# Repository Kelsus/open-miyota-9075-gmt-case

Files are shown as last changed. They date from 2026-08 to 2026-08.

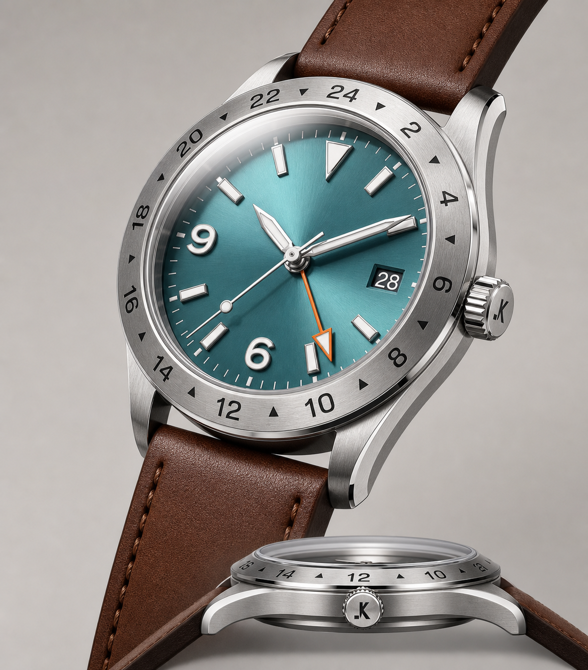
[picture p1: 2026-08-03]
mocks/fullwatchrender.png

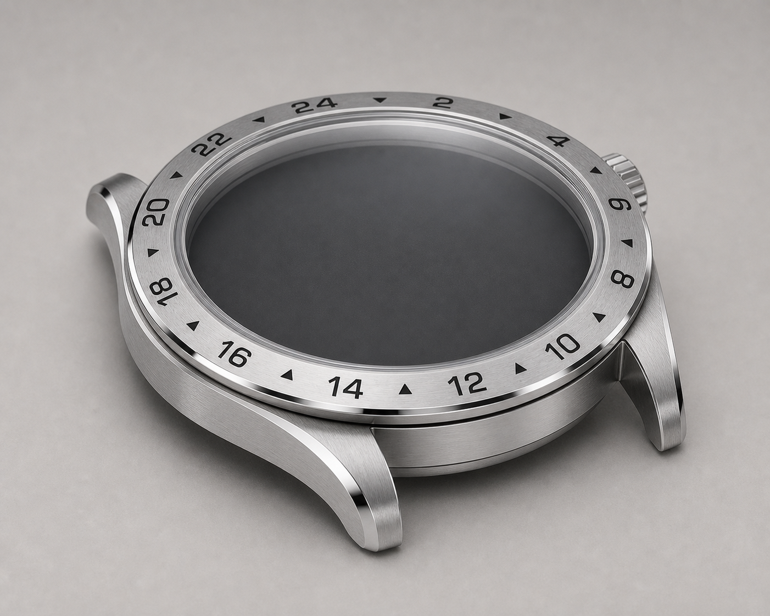
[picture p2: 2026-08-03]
mocks/threequarterviewofcase2.png

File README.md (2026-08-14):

# Open Miyota 9075 GMT case

## Why? (written by Jon Christensen)
I have been enjoying building watches, and felt like it would be a fun 
challenge to try to build a true GMT. The most available true GMT 
movement is the Miyota 9075. Unfortunately, I couldn't find any cases
to go with this movement on AliExpress or any of the other main watch
mod community ecommerce sites.

I tried buying the cheapest complete watch I could find (A 
Tissel available here: [https://tisellkr.com/](https://m.tisellkr.com/product/tisell-miyota-9075-gmt/49/), 
but it doesn't have an exhibition caseback, and I didn't love the 
way the bezel looked.

Fable 5 is getting good enough to be able to work with as a partner
to do CAD design. So I worked with it to build this design. It probably
took longer with Fable as a partner than it would have taken an expert
CAD user, but I'm pretty happy with how it turned out. And given that
the point of this exercise is just to get my hands on a few watch 
cases, I figured, why not just donate this case to the world as an 
open source project!?

Feel free to use it however you want, mod it how you like, use it as a 
starting point for your real watches in your real watch company. You
don't even have to mention where the design came from.

## The details (mostly written by AI.)

A complete, parametric watch case for the Miyota 9075 GMT movement,
written in [CadQuery](https://cadquery.readthedocs.io/) and verified by
a 120-assertion test suite. The repository contains everything needed to
study the design, rebuild it from parameters, 3D print a snap-together
prototype, or send it to a machine shop: STEP files for all nine parts,
drawing callouts for the features STEP cannot carry, print-adapted STLs,
and the scripts that generate all of it.

**Design review site:**
[kelsus.github.io/open-miyota-9075-gmt-case](https://kelsus.github.io/open-miyota-9075-gmt-case/)
shows the current revision with renders, the full spec table, and the
verification status. It is `docs/index.html`, regenerated by
`build_review.py` from the same model as everything else.

The code is MIT licensed. The hardware design is licensed under
CERN-OHL-P v2, which is the hardware equivalent of MIT. You can build,
modify, and sell cases from these files. See [Licensing](#licensing).

## The design

A 39 mm GMT sports watch case with a bidirectional 120-click 24-hour
bezel, sapphire crystal, screw-down crown, and a threaded exhibition
caseback. The bezel top is coned so the watch wears thinner than its
stack height. The lugs are cut from a revolved ring, so their junction
with the case is circular by construction and needs no fillets.

| | |
|---|---|
| Movement | Miyota 9075 (GMT, 24 h hand), cased on a machined movement ring |
| Diameter | 39.0 mm |
| Lug to lug | 47.9 mm |
| Height | 12.0 mm to the crystal apex |
| Lug width | 20 mm, drilled, Ø1.35 spring-bar holes |
| Dial | Ø31.0 |
| Crystal | Ø31.4 flat-top domed sapphire, I-ring gasket |
| Caseback | M32 x 0.5 threaded ring, Ø21 sapphire window |
| Bezel | steel 24 h, bidirectional, 120 clicks, ball detent |
| Water resistance | designed to 10 ATM (untested; see Status) |
| Material | 316L |

Dimensions that interact with the movement come from the official Miyota
9075 casing drawing (907500C0): 5.12 mm height, stem at 2.55 below the
dial plane, Ø25.60 register, and a hand-pivot chain of 2.70 above the
dial seat. The drawing is copyrighted, so it is not in this repository.
Get it from [Miyota](https://www.miyotamovement.com/).

## Repository map

| Path | What it is |
|---|---|
| `case_model.py` | The design. One parameter dict is the spec sheet; everything downstream regenerates from it. |
| `verify_case.py` | 120 hard assertions: stack heights, fits, clearances, sapphire stress, thread and gasket geometry, mesh-level regression checks. Run it after any change. |
| `scan_step.py` | Screens exported STEP files for geometry that breaks CAD importers (degenerate faces, self-intersecting shells). |
| `output/*.step` | The nine parts plus an assembly, ready for CAD or quoting. |
| `print_variant.py`, `PRINTING.md`, `output/print/` | FDM adaptation: snap fits replace the threads and the spring ring. Prints on a standard 0.4 mm nozzle; 0.2 mm recommended for the small parts. |
| `xometry_variant.py`, `xometry_drawings.py`, `output/xometry/` | CNC prototype kit with drawing sheets carrying the thread callouts and critical fits. |
| `MANUFACTURING.md` | How to get it made in metal: factory RFQ package and prototype-shop instructions. |
| `compare_mocks.py`, `mocks/` | Reference renders and a silhouette comparison harness used during design. |
| `render.py`, `build_review.py` | Preview renders and the single-file design review page (`docs/index.html`, served by GitHub Pages). |

## Building from source

```bash
python3 -m venv .venv
source .venv/bin/activate
pip install -r requirements.txt
python3 case_model.py     # writes output/*.step and *.stl
python3 verify_case.py    # 120 checks; exit 0 means all pass
```

The lug construction runs in a subprocess because OCCT segfaults are not
catchable in-process. If the build dies partway, run it again; the
subprocess retries are part of the design.

Two facts about the exports that will save you a bad afternoon:

1. **Threads are not modeled.** Threaded interfaces are plain cylinders
   at nominal diameter with the callout carried in drawings and comments
   (M32 x 0.5 caseback, S0.9 x 0.225 crown, tube press fits). If you
   send a STEP to a machine shop without the callouts, you get smooth
   bores.
2. **Exports are screened, not trusted.** OCCT booleans sometimes
   produce shells that import as phantom geometry in other CAD packages.
   `scan_step.py` gates every export; run it if you regenerate.

## 3D printing

`output/print/` contains a print-adapted variant: the caseback thread
becomes three cantilever snap tabs, the bezel spring ring becomes an
integral snap lip, the crystal and window get crush ribs, and the crown
gets a press pin. Print the included test coupon first to dial in your
printer's fit, then the case. PETG for the snap parts; PLA cracks.
Full instructions in [PRINTING.md](PRINTING.md).

## Making it in metal

[MANUFACTURING.md](MANUFACTURING.md) covers both routes: a watch case
factory (finished, polished, water-tested cases; this is how microbrands
work) and a prototype CNC shop (bare accurate metal, fast, no watch
finishing). `output/xometry/` is a ready-to-upload fitment kit for the
second route, with per-part drawing sheets and prototype substitutions
where true watch parts exceed general machining: a coarser caseback
thread, a pin crown instead of the threaded crown and tube, acrylic
instead of sapphire.

## Status

What has been done: the geometry is complete for all nine parts, passes
its 120 checks, imports into Fusion 360 without artifacts, and 3D prints
as a snap-together prototype. Every attachment is engineered and
documented: crystal gasket, bezel retention and detent, caseback thread
and O-ring, crown tube press fit, movement ring, spring bars.

What has not been done: no metal case has been machined from these files
yet, water resistance is a design target rather than a test result, and
the dial and hands are out of scope. Treat the design as a reviewed,
verified starting point, not a production-proven one. If you machine or
print it, open an issue with what you learn either way.

## Licensing

- **Software** (all `.py` files, the HTML template, and the docs): [MIT](LICENSE).
- **Hardware design** (the parametric geometry, STEP and STL files, and
  drawings; anything you manufacture from them):
  [CERN-OHL-P v2](LICENSE-HARDWARE), a permissive license that is the
  hardware equivalent of MIT.
- **Trademarks are not licensed.** The Kelsus name, the K monogram
  (`assets/kelsus-logo-k.svg`, also engraved on the crown and caseback),
  and the name Intercontinental identify Kelsus, Inc. If you make and
  distribute your own cases from this design, remove or replace the K
  and the names. The `kelsus_k_wire()` function and the engraving text
  parameters in `case_model.py` are the two places to change.

Both licenses disclaim warranty. A watch case holds a movement and sits
on a wrist; check the numbers yourself before trusting either.

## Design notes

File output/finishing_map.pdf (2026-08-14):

# Sheet 1 - Midcase

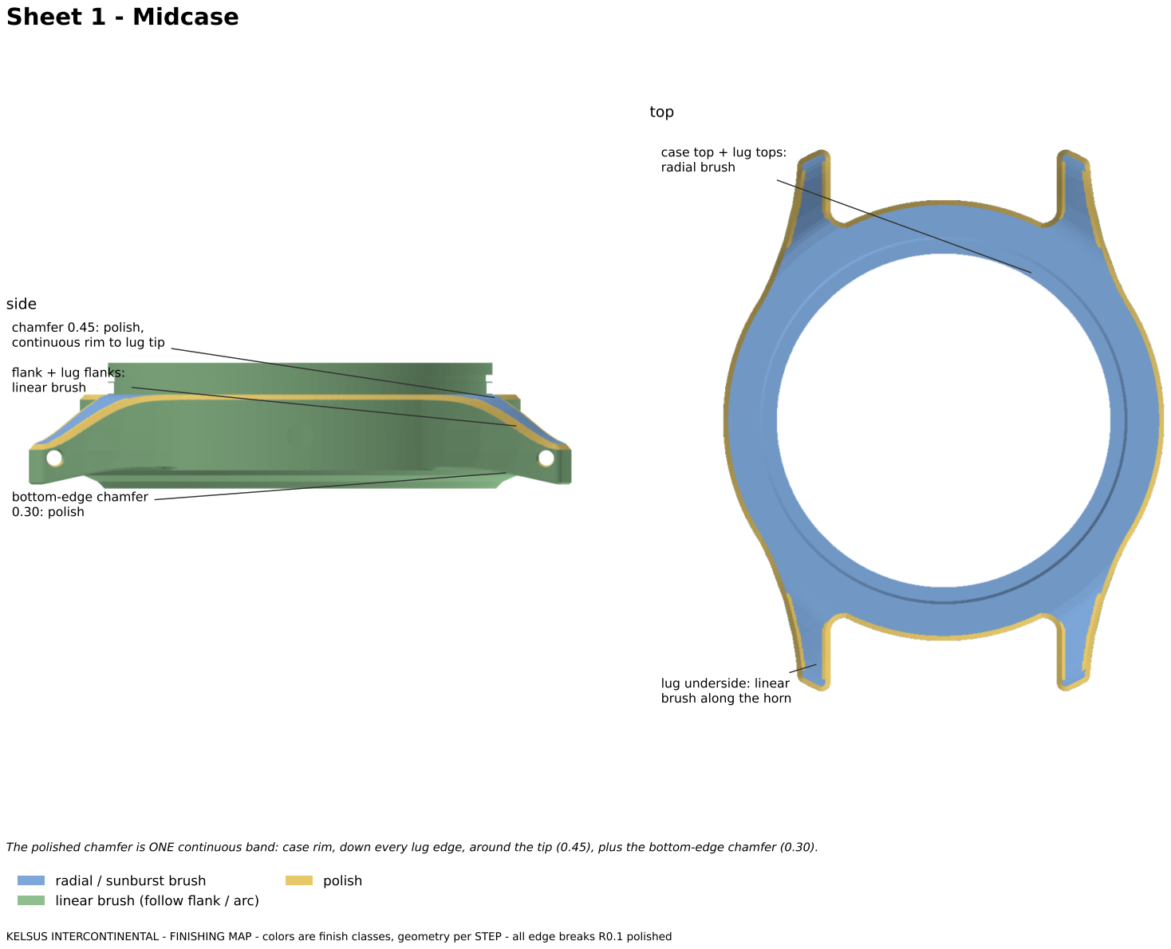
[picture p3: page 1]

flank + lug flanks:

linear brush

chamfer 0.45: polish,
continuous rim to lug tip

bottom-edge chamfer
0.30: polish

### side

case top + lug tops:
radial brush

lug underside: linear
brush along the horn

### top

The polished chamfer is ONE continuous band: case rim, down every lug edge, around the tip (0.45), plus the bottom-edge chamfer (0.30).

KELSUS INTERCONTINENTAL - FINISHING MAP - colors are finish classes, geometry per STEP - all edge breaks R0.1 polished

radial / sunburst brush
linear brush (follow flank / arc)

polish

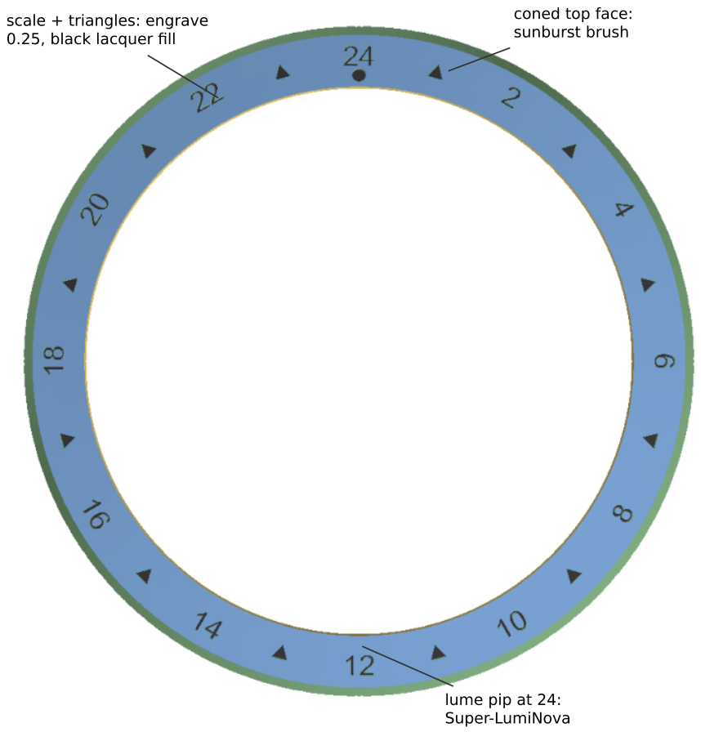
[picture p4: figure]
coned top face:; 0.25, black lacquer fill; lume pip at 24: Super-LumiNova

sunburst brush scale + triangles: engrave

### top

### side

# Sheet 2 - Bezel

radial / sunburst brush
linear brush (follow flank / arc)

polish
engraved (black lacquer fill on bezel)

# Sheet 3 - Caseback ring and crown

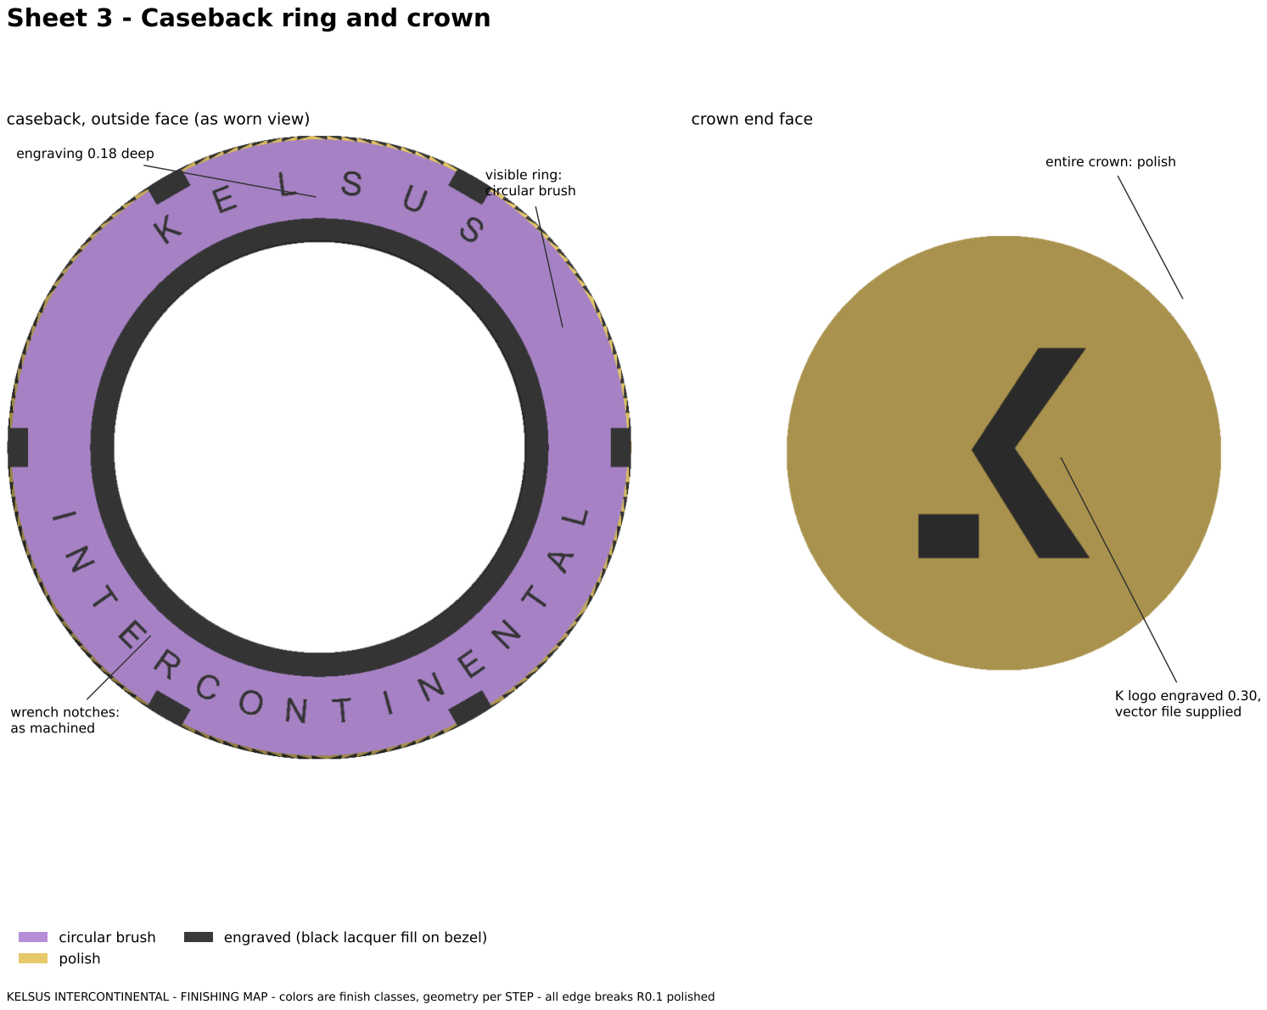
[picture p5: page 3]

visible ring:
circular brush

engraving 0.18 deep

wrench notches:
as machined

### caseback, outside face (as worn view)

entire crown: polish

K logo engraved 0.30,
vector file supplied

### crown end face

circular brush
polish

engraved (black lacquer fill on bezel)

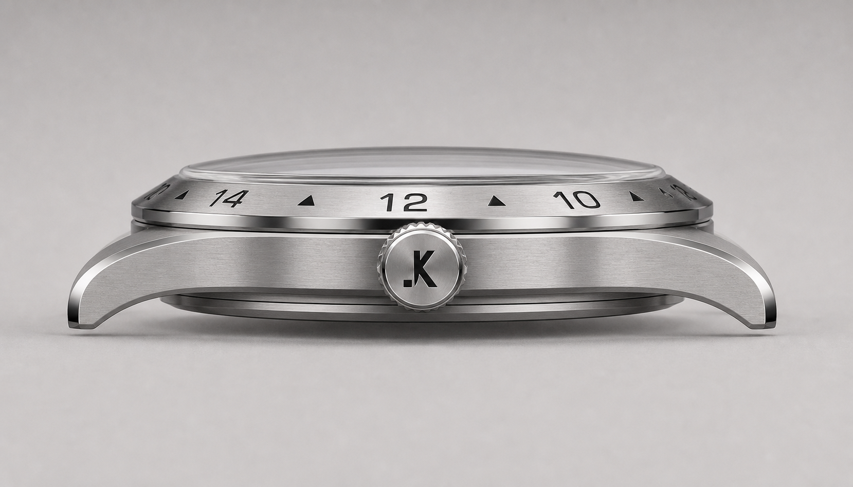
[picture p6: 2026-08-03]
mocks/crownsideviewofcase.png

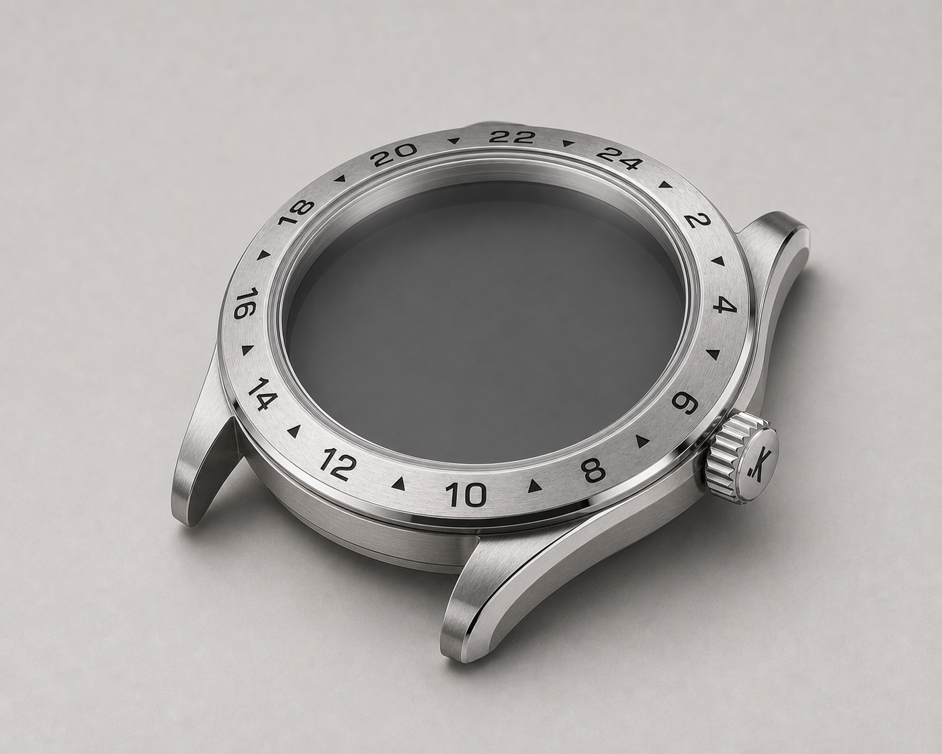
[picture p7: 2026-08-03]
mocks/threequarterviewofcase.png

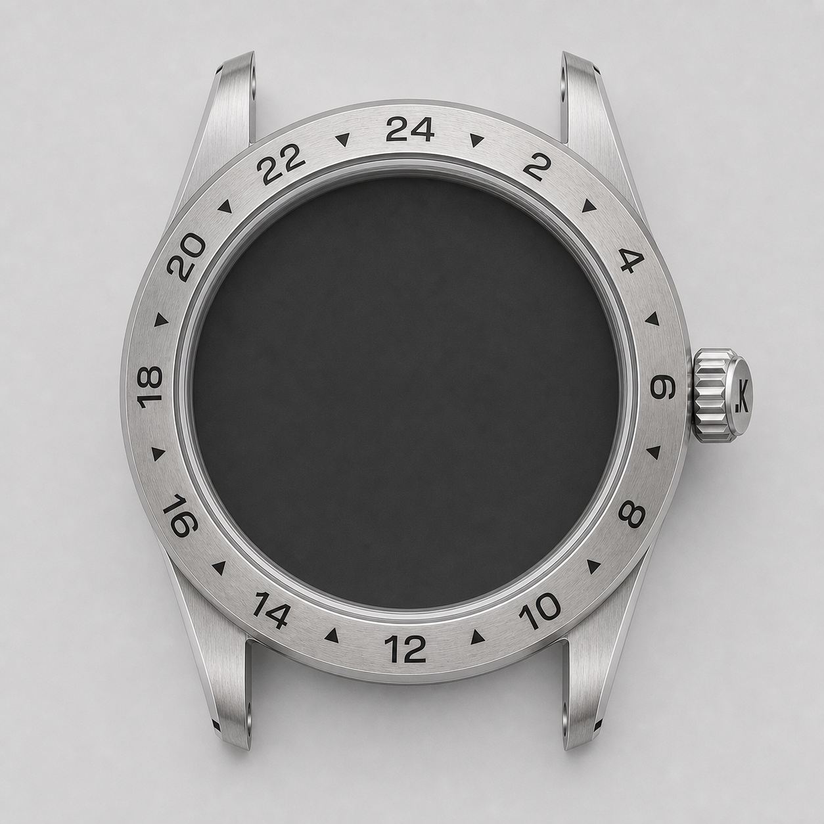
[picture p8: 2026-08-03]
mocks/topdownviewofcase.png

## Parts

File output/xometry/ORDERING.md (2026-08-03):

# Xometry order guide: fitment kit

Everything in this folder goes into one Xometry quote. Seven parts, all
1:1 with the master design except three prototype substitutions (coarser
caseback thread, pin crown instead of the threaded crown+tube, acrylic
instead of sapphire). Together they let you fully case a Miyota 9075:
movement + ring into the case, caseback screws in and sets the preload,
dial-side and hand clearance visible through the acrylic crystal, stem
alignment through the tube bore, bezel and crown for the complete look.

## Upload

Instant quote → CNC machining → upload all 7 STEPs. Then **attach
`intercontinental_fitment_kit_drawings.pdf` to every part.** The STEPs
carry no thread geometry; without the drawing you receive smooth bores
instead of threads.

## Per-part settings

| File | Process | Material | Finish | Qty |
|---|---|---|---|---|
| x01_midcase.step | CNC, 5-axis | Aluminum 6061-T6 | As machined (or bead blast) | 1 |
| x02_bezel.step | CNC | Aluminum 6061-T6 | As machined | 1 |
| x04_caseback.step | CNC | Aluminum 6061-T6 | As machined | 1 |
| x06_crown_proto.step | CNC (lathe) | Aluminum 6061 or 303 SS | As machined | 1 |
| x08_movement_ring.step | CNC | Acetal (Delrin/POM) | As machined | 1 |
| x03_crystal_acrylic.step | CNC | Acrylic (PMMA), clear | As machined | 1 |
| x05_window_acrylic.step | CNC | Acrylic (PMMA), clear | As machined | 1 |

Tolerance option: pick the tier that honors attached drawings (their
standard is a blanket ±0.13, which is not enough for the H7/Js8 fits;
the drawing callouts override where noted). Threads: M30×1.0 internal (case) and
external (back) are called out on sheets 1 and 3.

## Expect from DFM review

- Warnings on the tiny cosmetic features (0.25 engravings, 120 scallops,
  coin edge, Ø0.65 ball pocket). All are marked "best effort / may be
  omitted" on the drawings. Accept their recommendation; none affect
  fitment.
- Possible upcharge or pushback on the M30×1.0 internal thread and the
  deep 5-axis lug undersides. Both are legitimate work; pay it or ask
  for their alternative.
- If a part is rejected as unmachinable-at-price (most likely the coin
  edge or crown), drop the feature rather than the part.

## Budget guidance

The midcase (full 5-axis) dominates cost. If the quote shocks you, order
in two waves: **wave 1 = x01 + x04 + x08** (that's the complete movement
fitment test), wave 2 = bezel/crown/acrylics (look and feel). Aluminum
first; reorder the keepers in 316L once the fit is proven. Expect
roughly 3 to 5 times the aluminum price and a longer lead.

## When the parts arrive

1. Deburr check: run a fingernail around the dial pocket and crystal
   seat; any burr there scratches the dial.
2. Drop the 9075 (no dial) into the movement ring, ring into the case.
   It should register with zero rock.
3. Fit the dial (Ø31.0): it must clear the rehaut all round.
4. Stem check: cut a stem to length, thread into the movement, confirm
   it exits the Ø2.48 bore centered with no bind. Slide the crown pin in.
5. Caseback: screw in (M30×1.0). It should seat fully and just clamp the
   movement ring with no rattle. The design carries 0.02 preload; with
   ±0.05 aluminum tolerances expect anything from a light rattle to a
   light pinch. Note which you got, it calibrates the steel run.
6. Hands + acrylic crystal: press hands at 12:00:00, seat the crystal,
   verify hour/minute/GMT/seconds all clear the crystal underside.
7. Bezel: seat it on the boss over the groove. With no spring ring it
   lifts off again; that is expected. Check the reveal band is even and it clears the crystal.
8. Bracelet: spring bars through the Ø1.35 holes, end link against the
   Ø39 land, check for rock.

Log every deviation. That list is what gets tuned before the 316L run
or the factory RFQ.

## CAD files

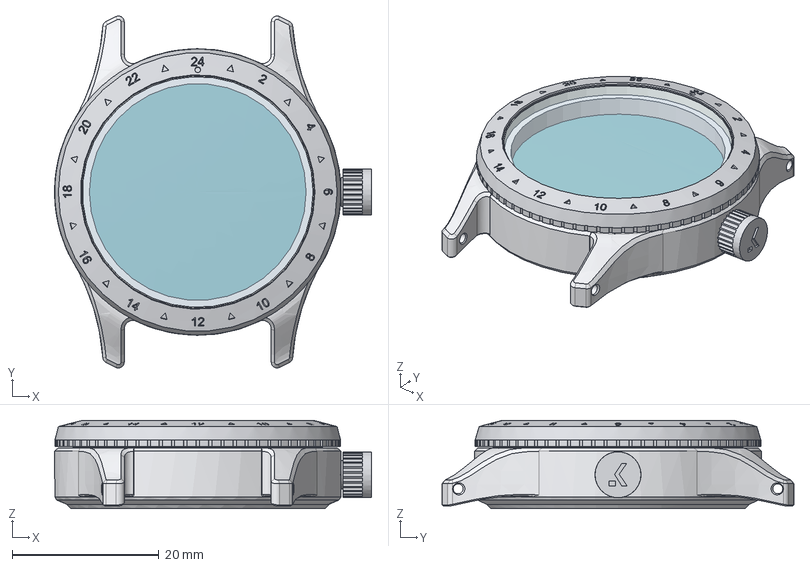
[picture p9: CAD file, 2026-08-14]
output/assembly.step
43.1 x 47.9 x 12.0 mm
midcase
bezel
crystal
caseback_ring
caseback_sap
crown
tube
movement_ring
bezel_spring
movement_ref
dial_ref
iring_gasket_installed
bezel_oring_installed

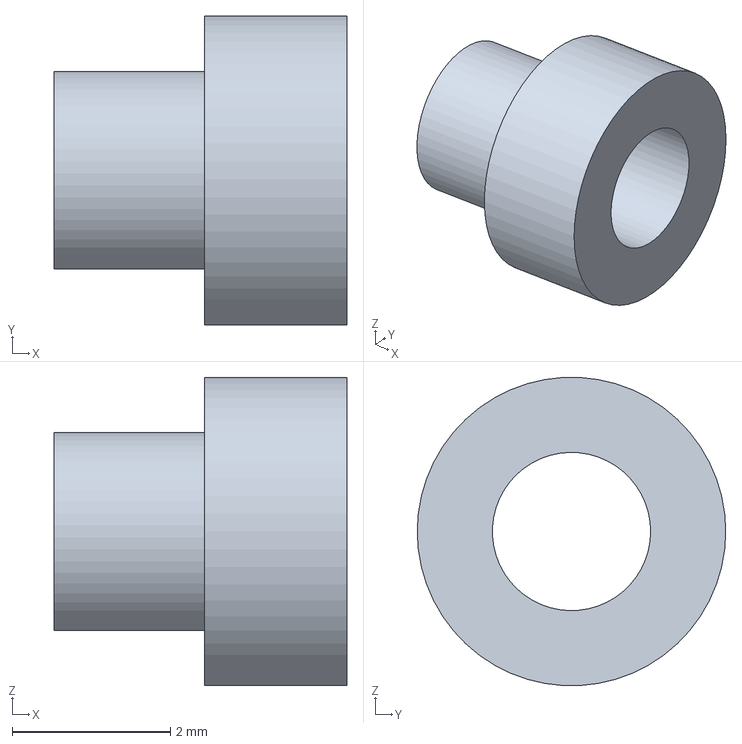
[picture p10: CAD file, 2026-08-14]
output/07_crown_tube.step
3.70 x 3.90 x 3.89 mm

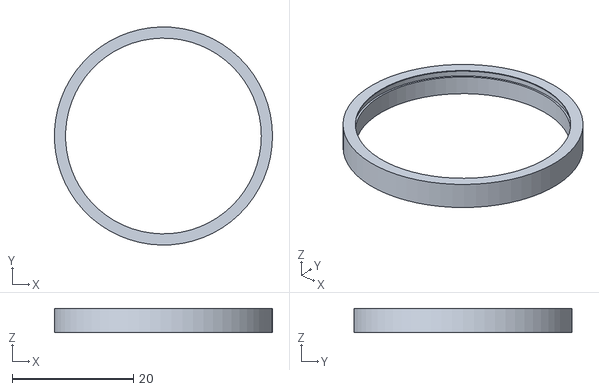
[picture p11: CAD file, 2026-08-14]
output/print/p00_snap_coupon.stl
36.0 x 36.0 x 4.00

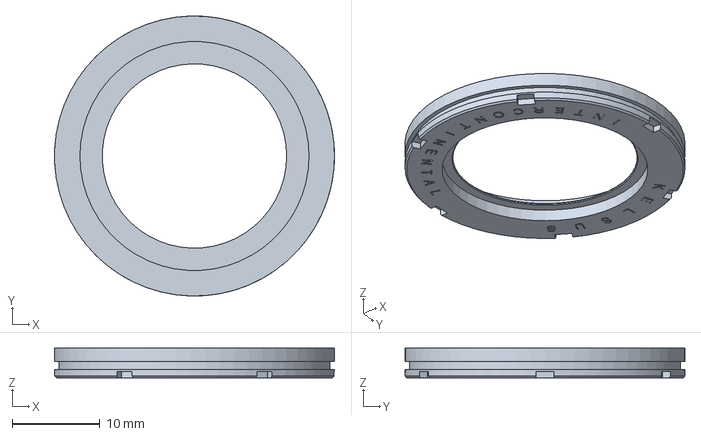
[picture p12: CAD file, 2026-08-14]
output/xometry/x04_caseback.step
31.9 x 31.9 x 3.40 mm

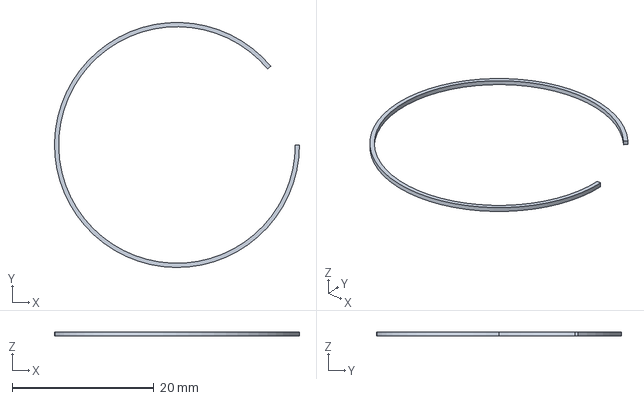
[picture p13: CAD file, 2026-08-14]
output/09_bezel_spring.step
34.6 x 34.6 x 0.6 mm

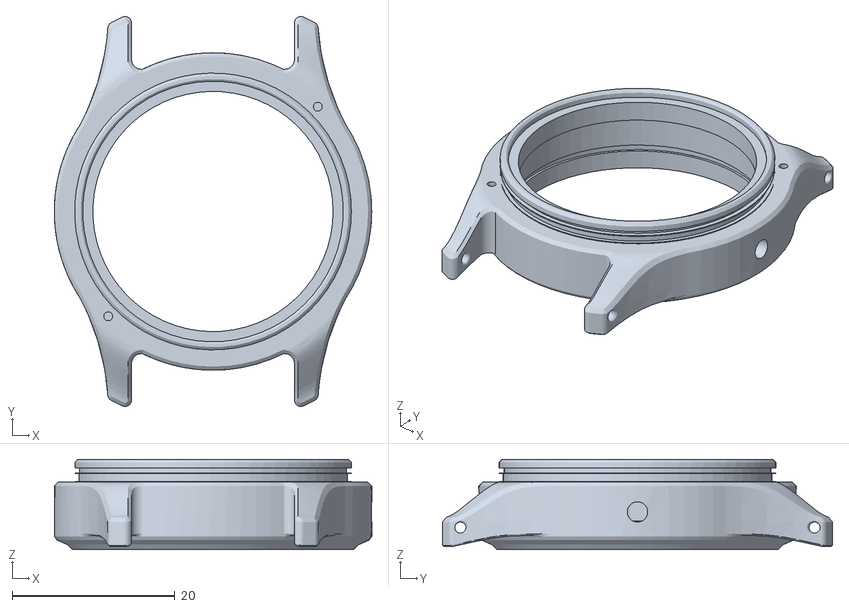
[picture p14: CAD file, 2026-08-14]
output/print/p01_case.stl
39.0 x 47.9 x 11.1

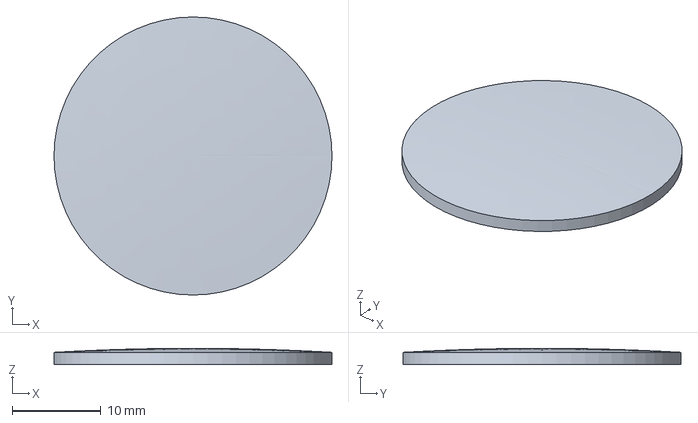
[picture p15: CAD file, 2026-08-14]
output/xometry/x03_crystal_acrylic.step
31.4 x 31.4 x 1.85 mm

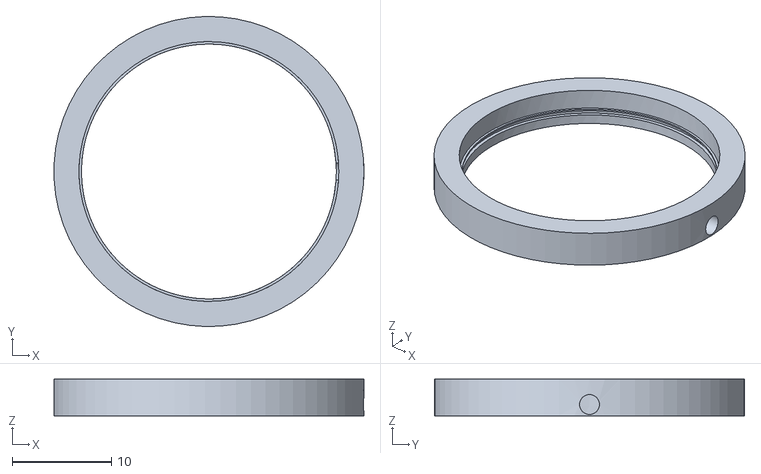
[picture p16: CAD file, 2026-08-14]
output/print/p08_movement_ring.stl
31.2 x 31.2 x 3.69

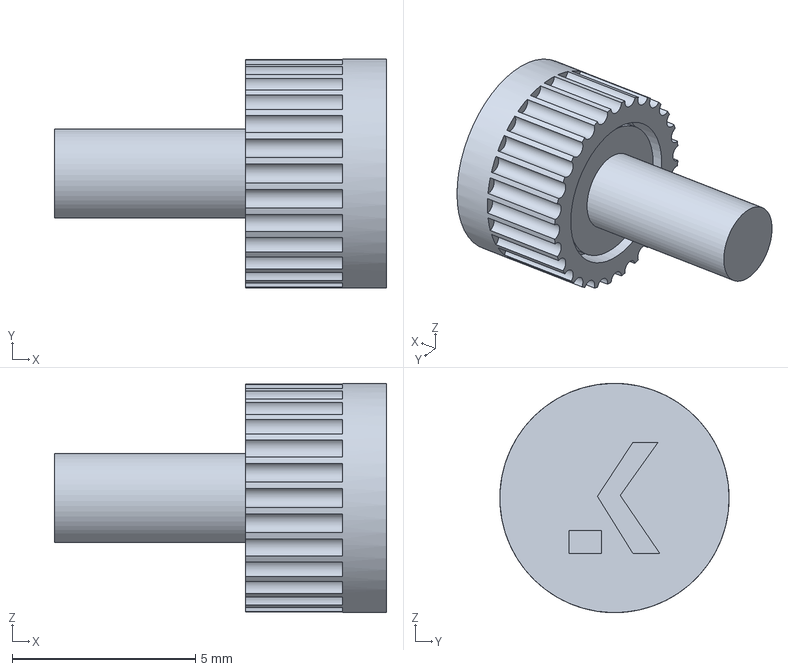
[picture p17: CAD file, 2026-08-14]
output/xometry/x06_crown_proto.step
9.05 x 6.25 x 6.25 mm

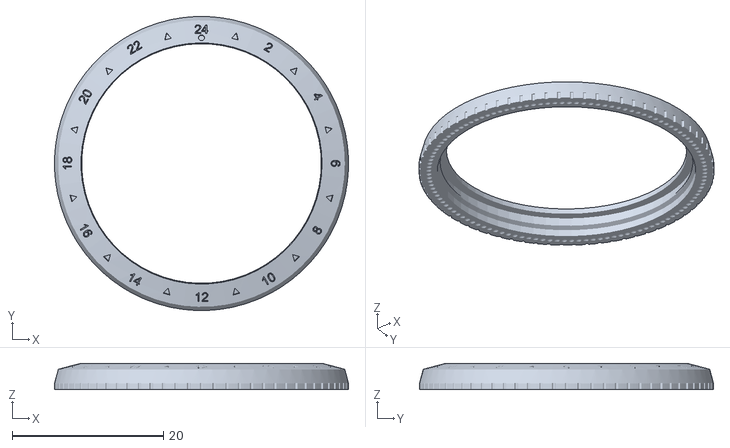
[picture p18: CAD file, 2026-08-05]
output/print/p02_bezel.stl
38.9 x 38.9 x 3.50

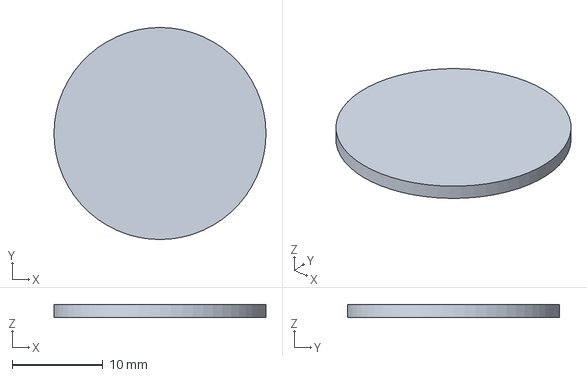
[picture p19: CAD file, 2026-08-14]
output/05_caseback_sapph.step
23.4 x 23.4 x 1.40 mm

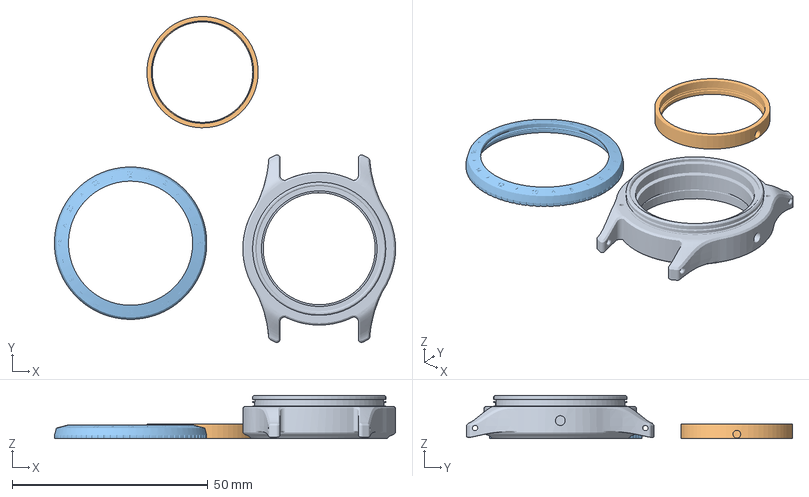
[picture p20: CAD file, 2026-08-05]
output/print/reprint_case.3mf
87.1 x 83.2 x 11.1 mm
p01_case.stl
p08_movement_ring.stl
p02_bezel.stl

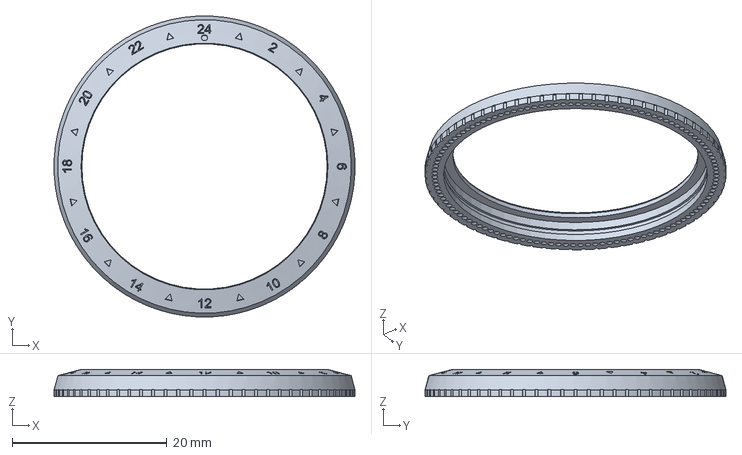
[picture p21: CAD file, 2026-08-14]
output/xometry/x02_bezel.step
38.9 x 38.9 x 3.50 mm

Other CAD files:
output/01_midcase.step
output/xometry/x08_movement_ring.step
output/08_movement_ring.step
output/print/p04_back.stl
output/xometry/x01_midcase.step
output/02_bezel.step
output/03_crystal.step
output/04_caseback_ring.step
output/06_crown.step
output/10_iring_gasket.step
output/11_bezel_oring.step
output/print/p03_crystal.stl
output/print/p05_window.stl
output/print/p06_crown.stl
output/print/print_case.3mf
output/print/testprint.3mf
output/xometry/x05_window_acrylic.step

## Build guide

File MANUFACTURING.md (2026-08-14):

# Getting the case made in metal

Two routes, and they answer different questions.

**Route A: a watch case factory.** You are buying a finished case:
machined, brushed and polished to watch grade, threads cut, sapphires
pressed with gaskets, crown and tube fitted, bezel clicking, water
tested, assembled. The factory sources the companion parts (sapphire,
gaskets, crown, tube, spring bars) from its local ecosystem for a few
dollars each. This is how microbrands work.

**Route B: a prototype CNC shop (Xometry, Protolabs, or similar).** You
are buying the exact geometry in the STEP file, in metal, fast, and
nothing else. No watch finishing (machine shop polishing is not watch
polishing), no gaskets, no sapphire, no assembly, no water resistance.
Everything after the machining is on you, and case finishing and crystal
pressing are hard to do well at home.

**Recommendation: both, in sequence.** Order the midcase from a
prototype shop in aluminum first, to hold the metal shape in hand and
check the bracelet fit, and send the full package to two or three case
factories for samples in parallel. Machining the full set at a prototype
shop in 316L costs more than factory samples and arrives less finished.
The exception is confidentiality: assume anything sent to a case factory
can be reused by them. If that is unacceptable, use Route B for
everything and accept the cost and the finishing work.

---

## The mistake to avoid

**The STEP files contain no thread geometry.** Threaded interfaces are
plain cylinders with the thread carried as a callout, which is standard
CAD/CAM practice. Upload a STEP to a quote engine without the callouts
and you get smooth bores. Every RFQ must carry these:

| Interface | Callout | Where |
|---|---|---|
| Caseback to case | M32 x 0.5, internal 6H (case), external 6g (back) | case bore Ø32.0 region, z 0 to 3.5 |
| Crown to tube | S0.9 x 0.225 (Miyota 9075 stem thread standard) | crown bore |
| Tube to case | press fit: tube shank Ø2.50 s6 into case bore Ø2.48 H7 | crown side, stem axis 4.62 above the back plane |
| Tube thread (crown screws onto it) | Ø3.9 x 0.35, depth 0.22 | tube OD |

## RFQ package contents

Send: `output/*.step` (9 parts plus the assembly), renders or the review
page for finish intent, reference images, and the spec tables below. Say
this in the cover message: the STEP is master geometry; threads and
finishes are per the spec sheet; where marked substitutable, the factory
may propose its standard equivalent parts.

### Critical dimensions (hold these)

| Feature | Dim | Tol |
|---|---|---|
| Case Ø | 39.00 | ±0.05 |
| Lug to lug | 47.90 | ±0.10 |
| Lug gap (bracelet) | 20.00 | +0.15 / −0 |
| Total height (back to crystal apex) | 12.02 | ±0.10 |
| Spring-bar holes | Ø1.35 ±0.05, 90° csk to Ø1.65 | position ±0.05 |
| Ø39.0 cylindrical end-link land | down to z 1.60 from the back plane | |
| Movement: Miyota 9075 | register Ø25.60 Js8, flange relief Ø26.0 x 2.05 deep | per Miyota drawing 907500C0 |
| Dial | Ø31.0; loads from the back through the caseback thread and pass bore, retained by the rehaut ledge | |
| Dial pass bore | Ø31.40 | H8 |
| Crystal bore | Ø32.00 H7; crystal Ø31.40 flat-top domed sapphire, I-ring gasket 0.35 wall, 0.10 diametral crush | |
| Bezel bore and boss | Ø34.10 bore on Ø34.00 boss, retention groove floor Ø32.80 | bore H8, boss h7 |
| Caseback sapphire | Ø23.4 x 1.4, view Ø21.0, pressed from outside against an internal ledge | |
| Stem axis height | 4.62 above the caseback plane | ±0.05 |

### Sealing (target 10 ATM, test to ISO 22810 at 10 bar)

- Caseback: radial O-ring, cs 0.70, in an OD groove (0.9 wide x 0.5 deep)
- Crown: O-ring cs 0.70 inside the crown, gasket at the tube
- Crystal: I-ring gasket, 0.35 wall (nylon or PA)
- Bezel: centring O-ring cs 0.70 in the boss groove (damping, not sealing)

### Bezel action

Bidirectional, 120 clicks. As designed: a spring-loaded ball in the case
shoulder rides 120 scallops (Ø0.50 ball seats, 0.18 deep, on Ø36.4) in
the bezel underside; the bezel is retained by a slit spring ring (part
09, free OD Ø34.6) engaging the boss groove. Substitutable: a factory's
standard ball click and spring washer retention is acceptable if the
bezel height, reveal, and exterior geometry are unchanged.

### Finishing map

`python3 build_finishing_map.py` renders this map as a color-coded PDF
(`output/finishing_map.pdf`) to attach to an RFQ.

- Case top faces and lug tops: radial brush
- Case flank: horizontal brush; lug flanks: brush following the arc
- All chamfers (shoulder 0.45, lug top, case bottom 0.30): polished
- Bezel coned top face: sunburst brush; long outer bevel: polished; coin edge: cut sharp
- Bezel numerals and triangles: engraved 0.25, black lacquer fill; lume
  pip Ø0.8 at the 24 position, recess 0.35 deep, Super-LumiNova fill
- Caseback ring: circular brush; engraving "KELSUS INTERCONTINENTAL"
  0.18 deep, filled or bare per sample
- Crown: polished, K logo engraved on the end face (SVG artwork in
  `assets/`; do not redraw it)
- Edge breaks everywhere else: R0.1 ("break sharp edges")

### Substitutable against not negotiable

The factory may substitute, with equivalents proposed in DFM: gaskets
and O-rings; the crown and tube as a bought-in assembly (with the K logo
face); the bezel click mechanism; the movement ring material (POM or
brass); the spring ring. Not negotiable: the exterior geometry and the
dimensions above, the movement interfaces, dial Ø31.0, stem height, the
bracelet interface, sapphire plus exhibition back, screw-down crown, and
the finishes.

---

## Route A: case factory, step by step

1. Shortlist 2 or 3 watch case factories rather than trading companies.
   Ask: do you machine in house, and can we video call the shop floor?
   Ask for microbrand references and a photo of a case they made with a
   coned engraved bezel and an exhibition back.
2. Send the RFQ package. Ask for DFM feedback, sample price and lead
   time, production MOQ and unit price at 50, 100, and 300, and a
   written change log. Factories normalize geometry to house standards
   without telling you; require every deviation from the STEP to be
   listed for approval.
3. Expect sample pricing in the rough range of $200 to $800 per complete
   case and 4 to 8 weeks (verify; these numbers move). Pay for samples
   from two factories in parallel; the extra cost is small and the
   comparison is worth it.
4. When samples arrive, inspect against the checklist below with a 9075
   and a dial blank on hand.
5. Then discuss production. Typical case MOQs are 50 to 100; some shops
   do 20 to 30 at a premium.

On IP: an NDA with a case factory is worth asking for and worth little.
Assume the geometry can end up in their catalog. If that is
unacceptable, use Route B at higher cost, or split parts across
suppliers.

## Route B: prototype CNC shop, step by step

A real data point first (August 2026): Xometry's instant quote for the
midcase alone, aluminum 6061, quantity 1, standard ±0.13 tolerance and
no threads, was $670. The threads and the tight fits from the drawings
would raise that. If a printed prototype has already answered the form
and fit questions, Route A samples deliver more per dollar; a US
instant-quote shop at quantity 1 is the most expensive way to hold this
case in metal. Cheaper metal options: overseas instant-quote CNC
services (JLCCNC, PCBWay, RapidDirect) quote the same uploads at a
fraction of the US price, and an SLM 316L metal print of the midcase
(rough surface, no working fits, real steel weight) runs cheaper still.

1. Upload `01_midcase.step`, and `02_bezel.step` if the look matters for
   this round. Process: CNC machining, 5-axis. Material: aluminum
   6061 for a fit check round; 316L later runs near 3 to 5 times the
   price and slower.
2. Attach a drawing or manufacturing notes PDF carrying the thread
   callouts and criticals from the tables above. Without an attached
   drawing everything defaults to a blanket tolerance near ±0.13 and
   smooth bores. `output/xometry/` contains a ready-made fitment kit
   with per-part drawing sheets.
3. Finish: as machined or bead blast. Do not pay for shop polishing on a
   fit check.
4. Skip at the prototype shop: crown, tube, spring ring, gaskets, and
   sapphires. These are bought parts (crown and tube from a watch parts
   supplier, sapphires from a sapphire house).

## Sample inspection checklist (either route)

- [ ] 9075 plus movement ring drops into the register; no rock; clamp screws reach
- [ ] Stem hole aligns with the movement stem (height 4.62, no bind on a real stem)
- [ ] Dial Ø31.0 seats in the pocket; no rehaut shadowing at the edge
- [ ] Caseback threads in for 4 or more full turns, seats with the gasket, notches take a wrench
- [ ] Crystal pressed flush, no gasket extrusion visible, no stress rings
- [ ] Bezel: 120 clean clicks, no wobble, even reveal all round
- [ ] Crown: screws down and engages 3 or more turns (ask for orientation-timed threading only if the K angle matters; it costs)
- [ ] Bracelet: end link seats on the Ø39 land without rocking; spring bars go in and out without force
- [ ] Water test certificate at 10 bar
- [ ] Finish: brush grain directions per the map, lacquer fill clean in the numerals, engraving depth even
- [ ] Weight near 49 g for the bare 316L case

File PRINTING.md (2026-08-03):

# 3D printing the case

A 1:1 snap-together prototype of the case. It is a form, feel, and
assembly prototype: wrist presence, lug drape, bezel proportions, end
link and dial fit. It is not a functional watch case. The machined
design's fasteners are below FDM resolution (the M30 x 0.5 caseback
thread, the S0.9 crown thread, and the 0.35 mm steel bezel spring ring),
so `print_variant.py` derives adapted parts where every interface is a
snap or press fit sized for plastic. Files are in `output/print/`.

| File | Replaces | How it attaches |
|---|---|---|
| `p00_snap_coupon.stl` | nothing | 20 minute test ring: dial in the caseback snap before the long case print |
| `p01_case.stl` | 01 midcase | snap bore Ø30.30 with a groove replaces the thread; straight Ø2.5 crown hole; boss lead-in chamfer |
| `p02_bezel.stl` | 02 bezel + 09 spring ring | integral snap lip (Ø33.35) clicks over the boss into the retention groove and still rotates |
| `p03_crystal.stl` | 03 crystal + gasket | 6 crush ribs press into the Ø32.0 bore |
| `p04_back.stl` | 04 back + M30 thread | 3 cantilever snap tabs click into the case groove |
| `p05_window.stl` | 05 sapphire | clear disc, 3 crush ribs, presses into the back from outside |
| `p06_crown.stl` | 06 crown + 07 tube | integral Ø2.42 pin presses into the crown hole |
| `p08_movement_ring.stl` | 08 ring | drops into the case bore as designed |

`output/print/` also contains Bambu Studio project files (`*.3mf`) from
a successful print run on a Bambu Lab H2C with a 0.2 mm nozzle. If you
run Bambu Studio, open one of those and skip the setup below.

## Materials and nozzle

- **PETG** for the case, bezel, back, and movement ring. The snaps need
  PETG's strain headroom near 5 percent; PLA whitens or cracks on the
  caseback tabs and the bezel lip.
- **Clear PETG** or PC for the crystal and window. They print
  translucent rather than glass clear. For a clearer window, cut 1.5 mm
  acrylic to Ø23.2 and skip `p05`.
- Crown: any material.
- A **0.2 mm nozzle** is recommended for the bezel, crown, crystal, and
  window (numerals, coin edge, logo, ribs). 0.4 mm works for the case,
  back, coupon, and movement ring. With only a 0.4 mm nozzle everything
  still prints; the engraving detail is what you lose.

## Slicer setup

Settings below are for Bambu Studio and carry over to any modern slicer.
Global for all parts: 0.08 to 0.12 mm layers, 4 walls, 25 percent gyroid
infill, seam position "Aligned" (put it at 12 o'clock on the case so it
hides between the lugs).

Per part:

| Part | Orientation on plate | Supports |
|---|---|---|
| coupon | as exported (flat) | none |
| case | caseback face down (as exported) | tree supports under the lug undersides only; with a dual-nozzle printer, use a support interface material that the body does not bond to, which leaves glassy undersides |
| bezel | skirt down (as exported) | none; the internal ceiling bridges Ø32 to Ø34, enable "thick bridges" |
| back | engraved face down (as exported) | none; the engraving prints into the first layers and stays legible |
| crystal | seat down, dome up | none |
| window | flat down | none |
| crown | logo face down, pin up | none |
| movement ring | flat down | none |

## Print order

1. **Print `p00_snap_coupon` and `p04_back` first.** Click the back into
   the coupon: it should seat with a firm push and a click, and take
   real effort to pry back out (pry at the wrench notches).
   - Too tight or no click: set X-Y hole compensation +0.05 to +0.10 on
     the coupon (and later the case), or sand the three bumps.
   - Too loose: go the other way, or reprint the back scaled 100.3
     percent in X-Y only.
   - Carry the winning compensation into the case print.
2. Print the case (the long print) and the rest in any order.

## Assembly

1. **Movement ring** drops into the case from the back, clamp band up.
2. **Crystal**: press into the top bore with a flat block until it stops
   on the seat. The bore's lead-in chamfer does the guiding.
3. **Bezel**: set it square on the boss and press straight down with
   both thumbs. The lip climbs the boss chamfer, snaps into the groove,
   and the bezel then spins with a little play. The prototype has no
   detent clicks; the 0.18 mm scallops and the ball are below printable
   scale.
4. **Caseback**: align and press until the three tabs click into the
   groove. Remove by pushing from the crystal side with the crystal
   out, or pry at the wrench notches.
5. **Window**: press into the back's pocket from the outside.
6. **Crown**: the printed crown hole comes out near Ø2.3 to 2.4. Run a
   2.4 mm drill through it if available, then press the crown pin in.
   Leave it dry so the depth can be adjusted; a dot of CA glue once it
   is right.
7. **Spring bars**: the Ø1.35 lug holes print near Ø1.15. Open them
   with a 1.4 mm drill, then fit Ø2.0 spring bars and end links as
   normal.

## What this prototype can and cannot tell you

**Good for:** wrist feel at 47.9 x 39 x 12.0, lug drape and stance,
bezel diameter and height proportions, end link and bracelet fit on the
Ø39 land, dial opening at Ø31, crown position and reach.

**Not representative:** thread feel, water resistance (none), bezel
detents, surface finish, weight (a PETG case is near 8 g against 49 g
in steel; add the movement and bracelet for a fairer wrist impression),
and the crystal optics.

**Real movement caution:** the case will hold a Miyota 9075 for a dial
and stem alignment check, but printed plastic sheds static and debris.
Keep the movement in its ring, dust it before it goes back into anything
that matters, and do not force the stem: printed hole tolerances are
plus or minus 0.1 at best.

## Regenerating

After any change to the master model:

```bash
python3 case_model.py && python3 print_variant.py
```

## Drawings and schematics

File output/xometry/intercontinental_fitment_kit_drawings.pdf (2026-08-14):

### CASEBACK THREAD

### CRYSTAL BORE

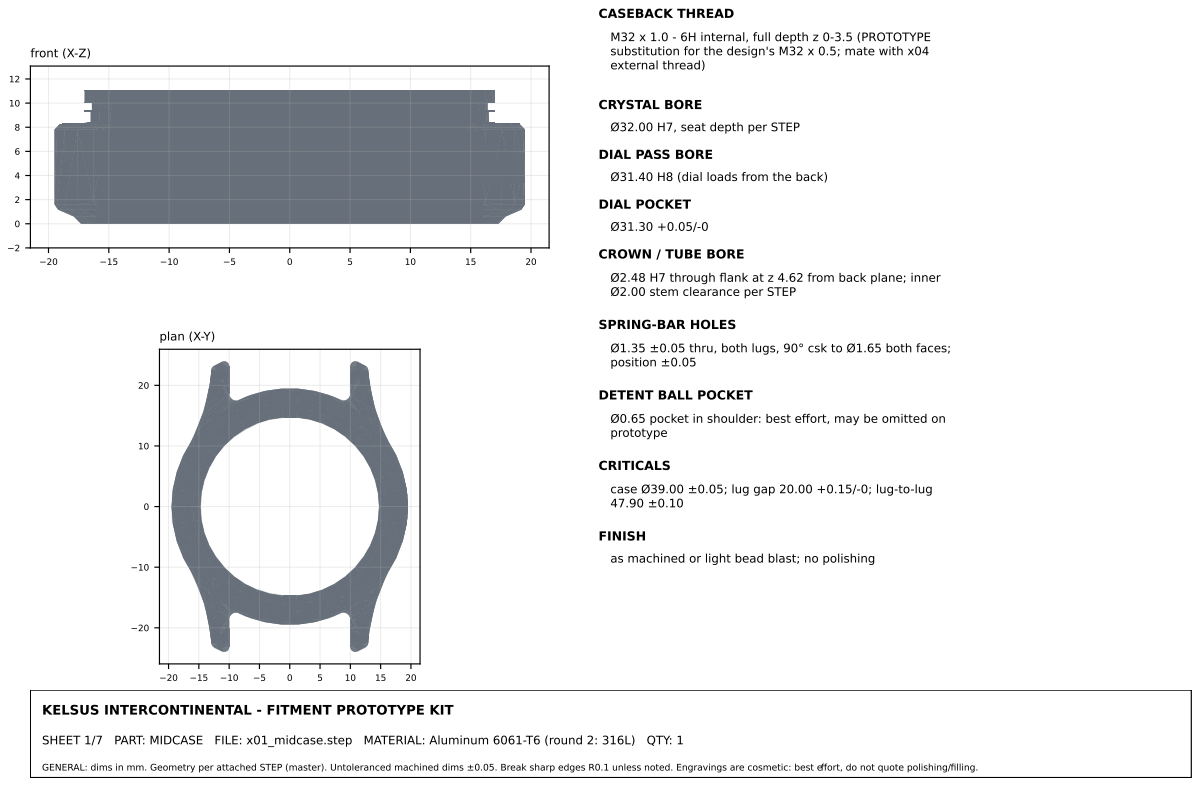
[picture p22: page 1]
front (X-Z); plan (X-Y); DIAL POCKET; CRITICALS; FINISH

M32 x 1.0 - 6H internal, full depth z 0-3.5 (PROTOTYPE
substitution for the design's M32 x 0.5; mate with x04
external thread)

Ø32.00 H7, seat depth per STEP

DIAL PASS BORE

Ø31.40 H8 (dial loads from the back)

CROWN / TUBE BORE
Ø2.48 H7 through flank at z 4.62 from back plane; inner
Ø2.00 stem clearance per STEP

SPRING-BAR HOLES

Ø1.35 ±0.05 thru, both lugs, 90° csk to Ø1.65 both faces;
position ±0.05

DETENT BALL POCKET
Ø0.65 pocket in shoulder: best effort, may be omitted on
prototype

case Ø39.00 ±0.05; lug gap 20.00 +0.15/-0; lug-to-lug

as machined or light bead blast; no polishing

KELSUS INTERCONTINENTAL - FITMENT PROTOTYPE KIT

SHEET 1/7 PART: MIDCASE FILE: x01_midcase.step MATERIAL: Aluminum 6061-T6 (round 2: 316L) QTY: 1

GENERAL: dims in mm. Geometry per attached STEP (master). Untoleranced machined dims ±0.05. Break sharp edges R0.1 unless noted. Engravings are cosmetic: best effort, do not quote polishing/filling.

### BORE

### INTERNAL GROOVE

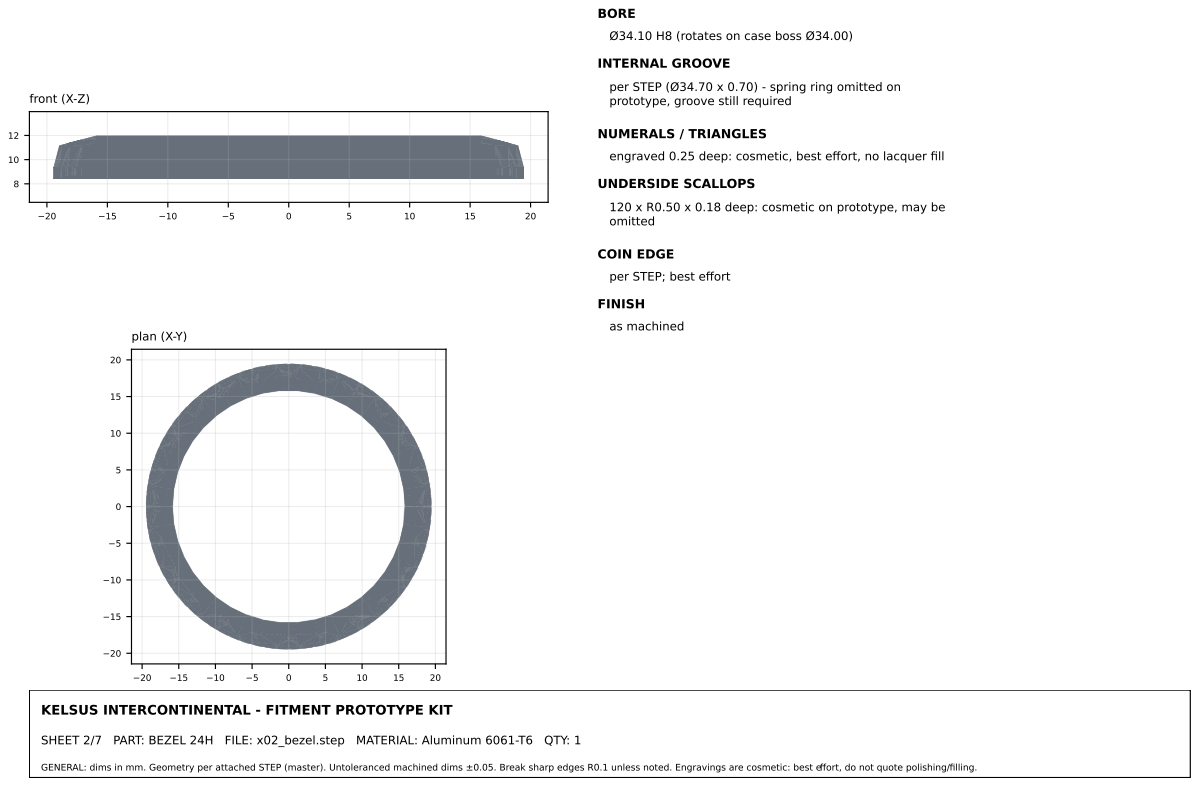
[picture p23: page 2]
front (X-Z); plan (X-Y); UNDERSIDE SCALLOPS; FINISH; as machined

Ø34.10 H8 (rotates on case boss Ø34.00)

per STEP (Ø34.70 x 0.70) - spring ring omitted on
prototype, groove still required

NUMERALS / TRIANGLES
engraved 0.25 deep: cosmetic, best effort, no lacquer fill

120 x R0.50 x 0.18 deep: cosmetic on prototype, may be
omitted

COIN EDGE
per STEP; best effort

KELSUS INTERCONTINENTAL - FITMENT PROTOTYPE KIT

SHEET 2/7 PART: BEZEL 24H FILE: x02_bezel.step MATERIAL: Aluminum 6061-T6 QTY: 1

### THREAD

### O-RING GROOVE

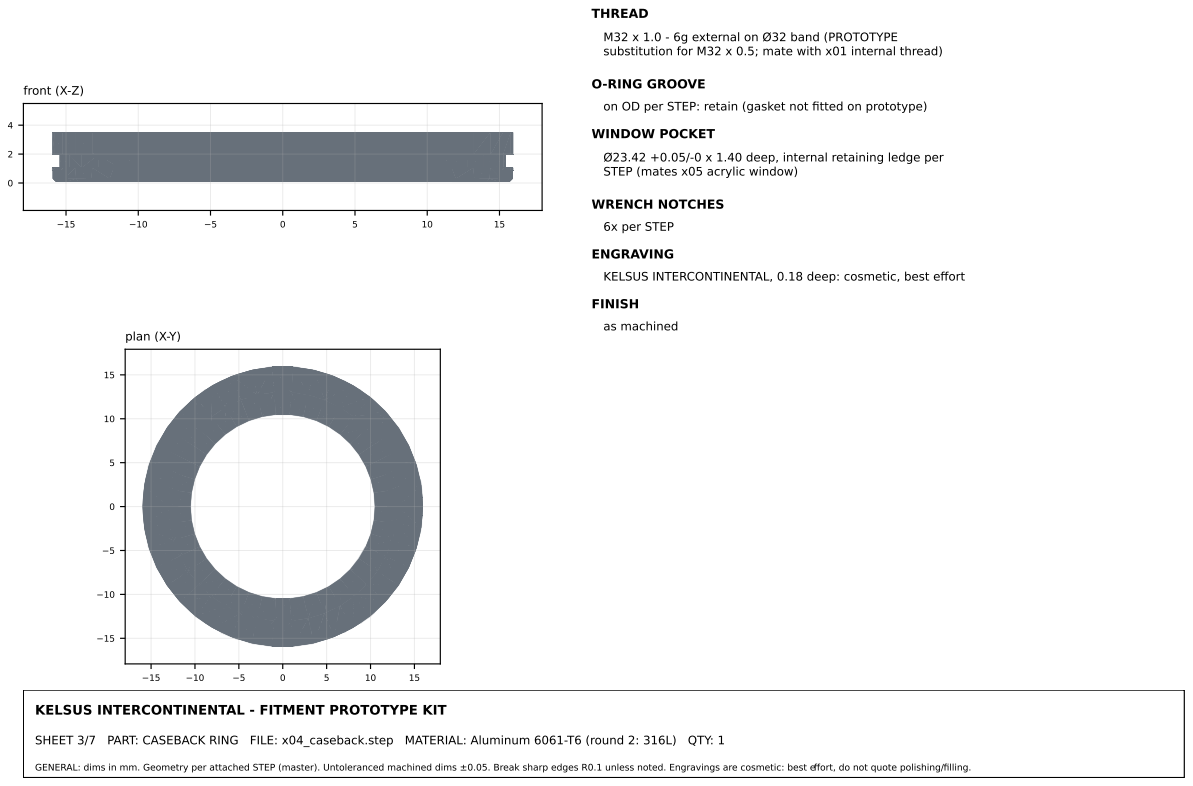
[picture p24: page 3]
front (X-Z); plan (X-Y); WINDOW POCKET; WRENCH NOTCHES; 6x per STEP; FINISH; as machined

M32 x 1.0 - 6g external on Ø32 band (PROTOTYPE
substitution for M32 x 0.5; mate with x01 internal thread)

on OD per STEP: retain (gasket not fitted on prototype)

Ø23.42 +0.05/-0 x 1.40 deep, internal retaining ledge per
STEP (mates x05 acrylic window)

ENGRAVING
KELSUS INTERCONTINENTAL, 0.18 deep: cosmetic, best effort

KELSUS INTERCONTINENTAL - FITMENT PROTOTYPE KIT

SHEET 3/7 PART: CASEBACK RING FILE: x04_caseback.step MATERIAL: Aluminum 6061-T6 (round 2: 316L) QTY: 1

### MOVEMENT REGISTER

### FLANGE SEAT

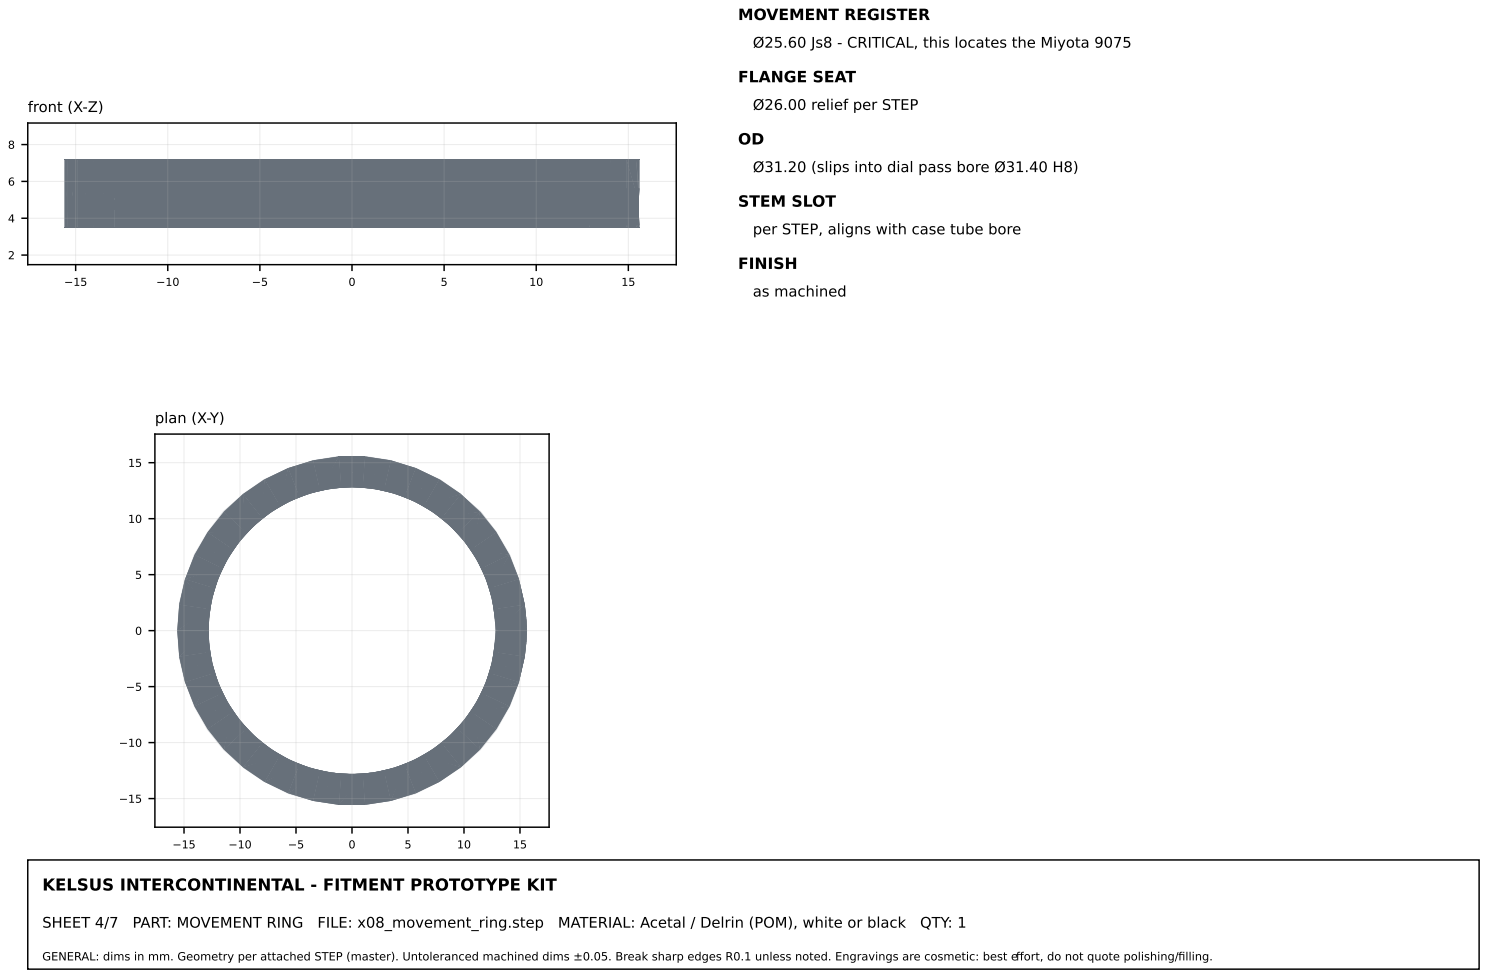
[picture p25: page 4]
front (X-Z); plan (X-Y); STEM SLOT; FINISH; as machined

Ø25.60 Js8 - CRITICAL, this locates the Miyota 9075

Ø26.00 relief per STEP

Ø31.20 (slips into dial pass bore Ø31.40 H8)

per STEP, aligns with case tube bore

KELSUS INTERCONTINENTAL - FITMENT PROTOTYPE KIT

SHEET 4/7 PART: MOVEMENT RING FILE: x08_movement_ring.step MATERIAL: Acetal / Delrin (POM), white or black QTY: 1

OD

### PROFILE

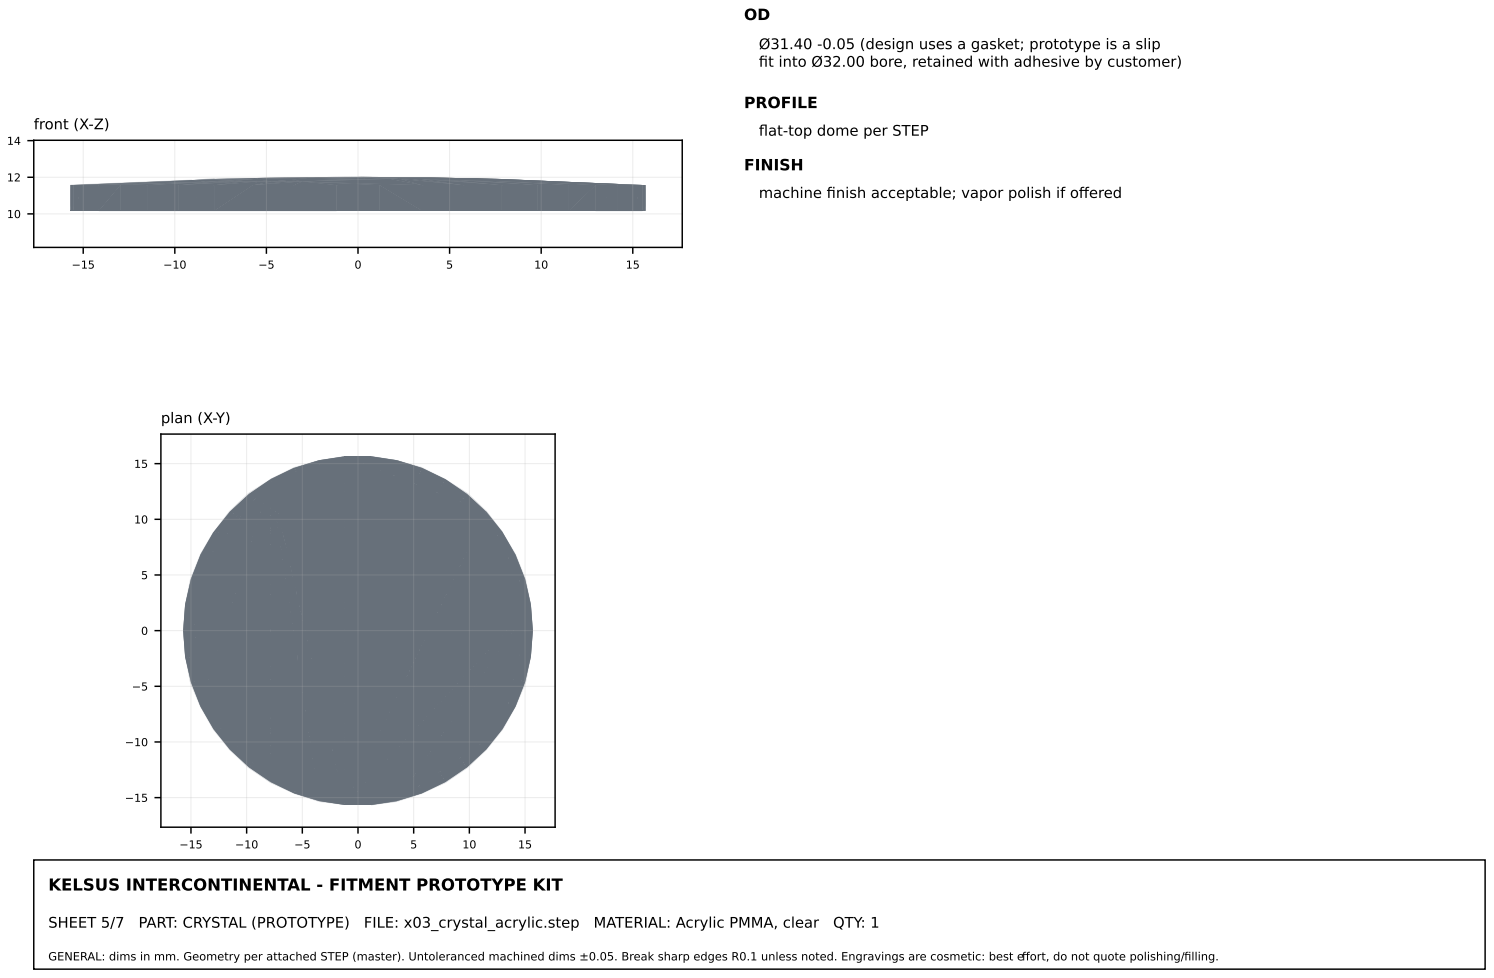
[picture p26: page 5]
front (X-Z); plan (X-Y)

Ø31.40 -0.05 (design uses a gasket; prototype is a slip
fit into Ø32.00 bore, retained with adhesive by customer)

flat-top dome per STEP

FINISH
machine finish acceptable; vapor polish if offered

KELSUS INTERCONTINENTAL - FITMENT PROTOTYPE KIT

SHEET 5/7 PART: CRYSTAL (PROTOTYPE) FILE: x03_crystal_acrylic.step MATERIAL: Acrylic PMMA, clear QTY: 1

### DISC

### FINISH

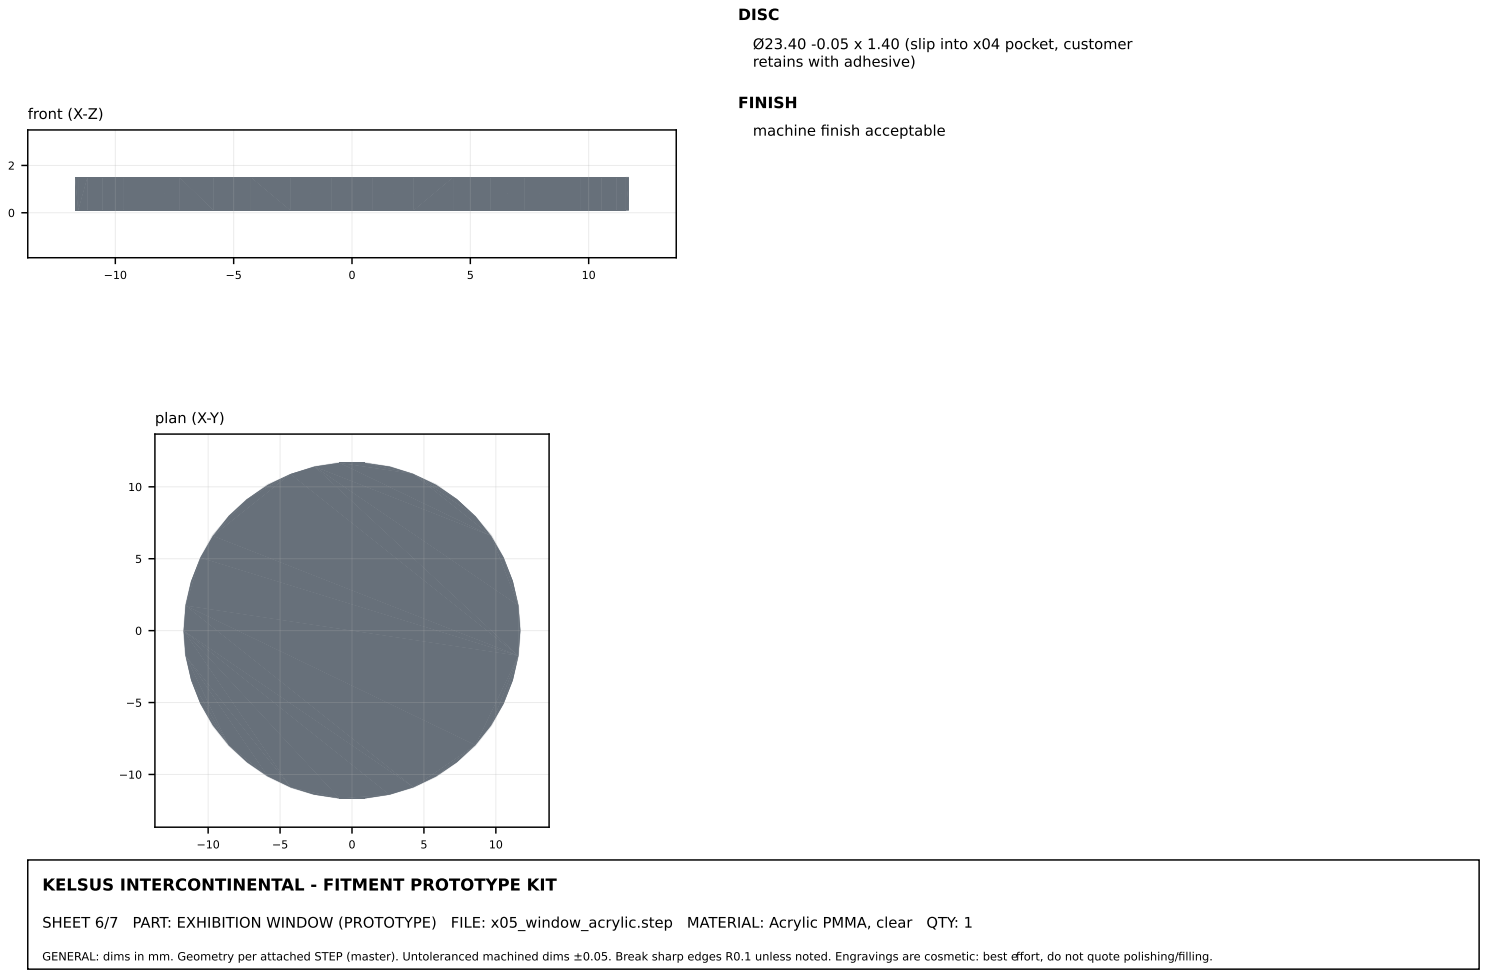
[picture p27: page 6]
front (X-Z); plan (X-Y)

Ø23.40 -0.05 x 1.40 (slip into x04 pocket, customer
retains with adhesive)

machine finish acceptable

KELSUS INTERCONTINENTAL - FITMENT PROTOTYPE KIT

SHEET 6/7 PART: EXHIBITION WINDOW (PROTOTYPE) FILE: x05_window_acrylic.step MATERIAL: Acrylic PMMA, clear QTY: 1

### PIN

### BODY

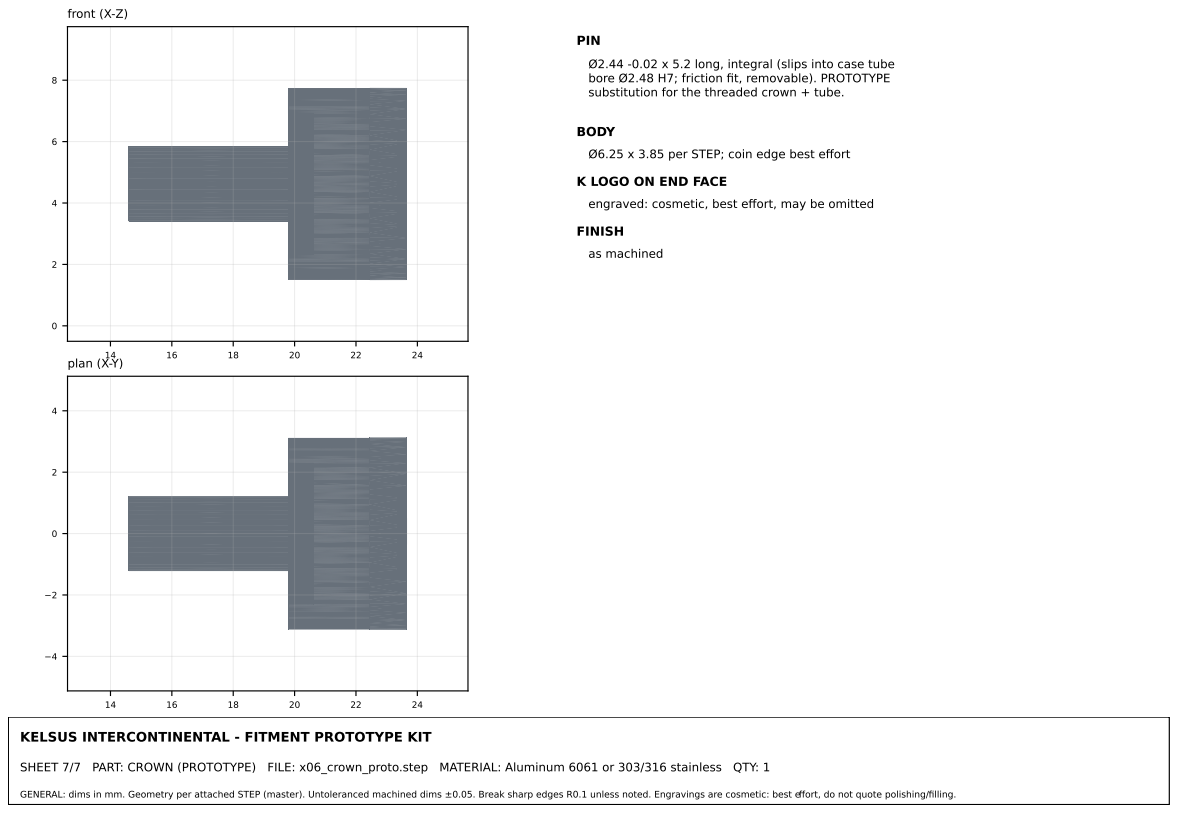
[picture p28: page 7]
front (X-Z); plan (X-Y); FINISH; as machined

Ø2.44 -0.02 x 5.2 long, integral (slips into case tube
bore Ø2.48 H7; friction fit, removable). PROTOTYPE
substitution for the threaded crown + tube.

Ø6.25 x 3.85 per STEP; coin edge best effort

K LOGO ON END FACE
engraved: cosmetic, best effort, may be omitted

KELSUS INTERCONTINENTAL - FITMENT PROTOTYPE KIT

SHEET 7/7 PART: CROWN (PROTOTYPE) FILE: x06_crown_proto.step MATERIAL: Aluminum 6061 or 303/316 stainless QTY: 1

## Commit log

2026-08-03 Open Miyota 9075 GMT case: parametric CadQuery design, verification, and manufacturing packages
    39 mm GMT case for the Miyota 9075: 9-part parametric model
    (case_model.py), 113-assertion verification suite, STEP exports,
    FDM snap-together print variant, CNC fitment kit with drawing
    sheets, and factory RFQ documentation.
    Code under MIT, hardware design under CERN-OHL-P v2, Kelsus
    trademarks excluded.
    [01_midcase.step, 02_bezel.step, 03_crystal.step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]
2026-08-04 Add real Xometry quote data point to Route B guidance
    Midcase alone quoted $670 in 6061 at quantity 1 with no threads.
    Document cheaper metal options and when to skip Route B.
2026-08-05 Fix crown proto export: fuse fill and pin into one solid
    The bore fill was sized 0.005 under the bore, so it never touched the
    crown and the exported STEP carried two disjoint bodies (flagged by a
    machine shop's DFM review). The fill now interferes with the bore wall
    and runs past the bore bottom; exports assert a single fused solid.
    [p06_crown.stl, reprint_case.3mf, x06_crown_proto.step]
2026-08-05 Fix disjoint-body exports flagged by machine-shop DFM review
    The single-solid export guard caught three latent defects: the bezel
    snap lip anchored at the nominal bore radius floated inside the
    spring-ring groove as a loose ring; the caseback tab feet were severed
    because the slit and relief cutters overlapped in one compound (OCCT
    fragments self-overlapping boolean tools) and the O-ring groove crossed
    the tab feet; the crown bore fill never touched the crown. All print
    and CNC parts now assert one fused solid before export.
    [p02_bezel.stl, p04_back.stl]
2026-08-10 Fix caseback bottom-arc engraving direction; deterministic finishing map colors
    INTERCONTINENTAL read right-to-left in the as-worn view: bottom-arc
    words must progress counterclockwise to read left-to-right. Present
    since the engraving was added; the finishing map's as-worn rendering
    exposed it. Map classifier now colors only the deterministic rim
    chamfer as polish (the facet-size heuristic speckled the lug tops).
    [01_midcase.step, 02_bezel.step, 03_crystal.step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]
2026-08-10 Finishing map: continuous polished chamfer band rim-to-lug-tip
    Chamfer facets share their normal band with the diving lug top, so
    per-facet classification either speckled or truncated the band at the
    lug roots. The chamfer always lies in the plan-silhouette edge strip:
    rasterize the plan mask, erode it for the strip, and resolve ambiguous
    facets per pixel against it. The polished band now renders as one
    smooth stripe from case rim to lug tip.
2026-08-12 Expand README with project motivation and details
    Added a section explaining the motivation behind the project and the design process for the watch case.
2026-08-14 Rev G: back-loading dial architecture (factory DFM fix)
    The factory's DFM review found the dial could not be assembled: the
    Ø31.3 dial pocket was enclosed by smaller openings on every side (Ø30
    caseback thread, Ø28.6 bore, Ø29.5 rehaut), unbuildable since Rev C.
    The dial and movement now load from the back: caseback thread M32 x
    0.5, Ø31.40 H8 dial pass bore, movement ring OD Ø31.20, dial retained
    by the rehaut ledge with 0.05 clearance. New permanent assembly-path
    check; new gasket solids (10 I-ring, 11 bezel O-ring) at factory
    request. 120/120 checks pass.
    [01_midcase.step, 02_bezel.step, 03_crystal.step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]
2026-08-14 Assembly carries installed-state gasket reference bodies
    The free-state gasket solids (10, 11) are for the gasket vendor; the
    assembly now also shows both gaskets at installed dimensions
    (compressed I-ring annulus, squashed O-ring section) so a section view
    reads the sealing stack correctly. 13 solids in assembly.step.
    [01_midcase.step, 02_bezel.step, 03_crystal.step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]
